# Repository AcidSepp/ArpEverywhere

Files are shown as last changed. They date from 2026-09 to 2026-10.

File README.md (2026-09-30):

# ArpEverywhere
This project aims to bring Hold and Arp to Synthesizers that do not have it.

Adding Hold and Better Arp to the Korg Minilogue (https://www.youtube.com/watch?v=hi0-8F53ltk)

## BOM
- Microcontroller
  - 1x Arduino Nano ESP32
  - 1x 32 PIN DIP Socket, 15. (wide)
- ICs
  - 2x 6n128 Optocoupler
  - 2x 8 PIN DIP Socket
- Switches
  - 4x Toggle Switch
  - 2x 12 Way Rotary Switch
- Sockets
  - 4x MIDI 5Pin DIN Panel Mount Socket
- Resistors
  - 2x 480-1KΩ
  - 2x 4.7KΩ
  - 2x 10Ω
  - 2x 20Ω
  - 2x 100Ω
  - 24x 1kΩ
  - 4x 10kΩ
  - 2x 220Ω
- Diodes
  - 2x 1n914 Diode
- Connectors
  - 6x 2.54mm 0.1" Pitch PCB Mount Screw Terminal Block
- Prototype Board

## MIDI IN Circuit
The MIDI IN circuit is based on the [MIDI IN circuit form Notes And Volts](https://www.notesandvolts.com/2015/02/midi-and-arduino-build-midi-input.html).
Modifications to make it compatible with 3.3V:
- Connect Pin 8 of the optocoupler to +5V.
- Connect Pin 6 of the optocoupler to the RX Pin and to +3.3V via a 480-1KΩ resistor.

## MIDI OUT Circuit
The MIDI OUT circuit is based on the [MIDI OUT circuit from Notes And Volts](https://www.notesandvolts.com/2015/03/midi-for-arduino-build-midi-output.html).
Modifications to make it compatible with 3.3V:
- Connect Pin 4 of the MIDI Out Socket to +3.3V via a 30Ω resistor.
- Connect Pin 5 of the MIDI Out Socket to the TX Pin via a 10Ω resistor.

## Rotary Switch Circuit
The Rotary Switch Circuit is based on [Scotty D's circuit](https://www.youtube.com/watch?v=UbnNhUDheE8&t=487s).
I do not use the capacitor, and add another 1kΩ resitor at the end of the ladder.

## Toggle Switch Circuit
I used a standard toggle switch circuit with a 10KΩ pullup-resistor.

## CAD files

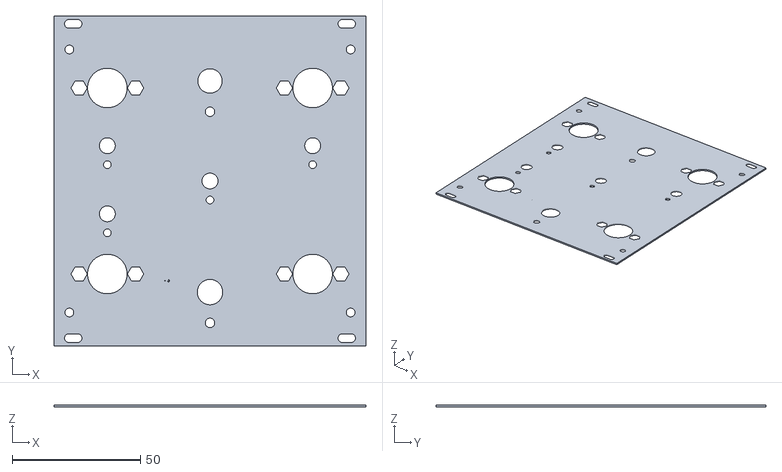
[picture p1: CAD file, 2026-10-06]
panels/frontPanel-backLayer.stl
121.6 x 128.5 x 0.8

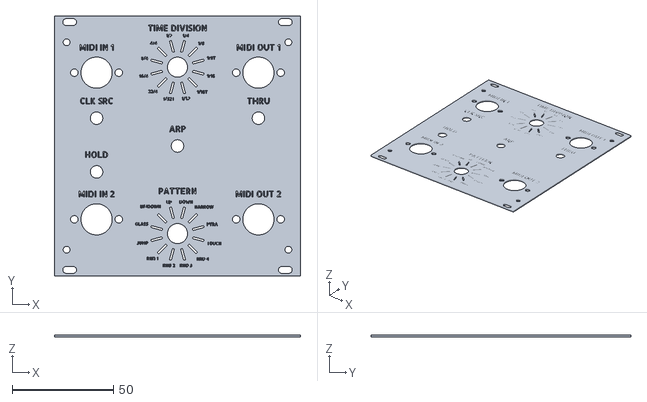
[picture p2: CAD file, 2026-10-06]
panels/frontPanel-frontLayer.stl
121.6 x 128.5 x 1.00

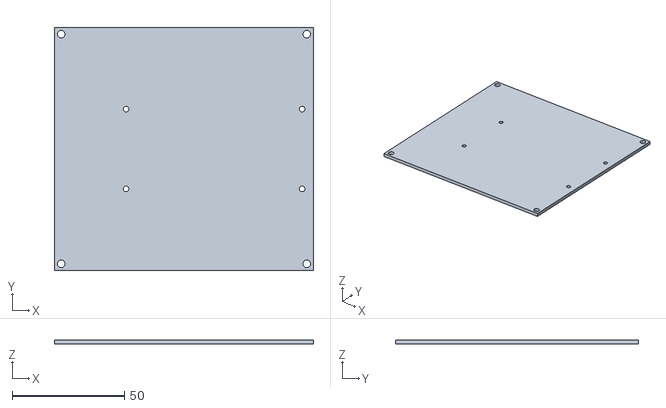
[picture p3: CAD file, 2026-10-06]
panels/backPanel.stl
115.6 x 108.5 x 2.00

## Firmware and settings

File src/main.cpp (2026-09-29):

#include <MIDI.h>

#include "Down.h"
#include "Hourglass.h"
#include "Jump.h"
#include "Narrow.h"
#include "rotarySwitch.h"
#include "timedivision.h"
#include "pattern.h"
#include "Pyramid.h"
#include "Random1.h"
#include "Random2.h"
#include "Random3.h"
#include "Random4.h"
#include "Touch.h"
#include "Up.h"
#include "UpDown.h"

constexpr bool DEBUG = false;

constexpr int MIDI_1_RX_PIN = 2;
constexpr int MIDI_1_TX_PIN = 3;
constexpr int MIDI_2_RX_PIN = 4;
constexpr int MIDI_2_TX_PIN = 5;

constexpr int HOLD_ON_OFF_SWITCH_PIN = 9;
constexpr int CLOCK_SRC_SWITCH_PIN = 8;
constexpr int ARP_ON_OFF_SWITCH_PIN = 7;
constexpr int MIDI_1_THRU_ON_OFF_SWITCH_PIN = 6;

constexpr int TIME_DIVISION_ROTARY_SWITCH_PIN = A1;
constexpr int PATTERN_ROTARY_SWITCH_PIN = A2;

HardwareSerial MidiSerial1(1);
HardwareSerial MidiSerial2(2);

MIDI_CREATE_INSTANCE(HardwareSerial, MidiSerial1, MIDI1);
MIDI_CREATE_INSTANCE(HardwareSerial, MidiSerial2, MIDI2);

static void noteOn(byte channel, byte note, byte velocity);

static void noteOff(byte channel, byte note, byte velocity);

static void handleClock();

constexpr int NOTES_ARRAY_SIZE = 128;

static bool pressedNotes[NOTES_ARRAY_SIZE];
static int pressedNotesCount = 0;
static bool sustainedNotes[NOTES_ARRAY_SIZE];
static int sustainedNotesCount = 0;
static bool holdFunctionActivated;
static bool arpActivated = true;
static int clockCounter = 0;
static TimeDivision timeDivision = _1_4;
static Pattern pattern = UP;
static bool clockFromMidi1 = true;
static bool midi1Thru = false;

static auto down = new Down();
static auto hourglass = new Hourglass();
static auto jump = new Jump();
static auto narrow = new Narrow();
static auto pyramid = new Pyramid();
static auto rnd2 = new Random2();
static auto rnd3 = new Random3();
static auto up = new Up();
static auto upDown = new UpDown();

static byte noteInputOrder[NOTES_ARRAY_SIZE];
static int noteInputOrderPointer = 0;
static auto touch = new Touch();

static void resetCounters() {
    clockCounter = 0;
    down->reset();
    hourglass->reset();
    jump->reset();
    narrow->reset();
    pyramid->reset();
    up->reset();
    upDown->reset();
}

static bool pressedNotesEmpty() {
    for (const bool pressedNote: pressedNotes) {
        if (pressedNote) {
            return false;
        }
    }
    return true;
}

static bool sustainedNotesEmpty() {
    for (const bool sustainedNote: sustainedNotes) {
        if (sustainedNote) {
            return false;
        }
    }
    return true;
}

static void clearSustainedNotes() {
    for (bool &sustainedNote: sustainedNotes) {
        sustainedNote = false;
    }
}

static void printSustainedNotes() {
    Serial.printf("Sustained Notes (%d): ", sustainedNotesCount);
    for (int i = 0; i < NOTES_ARRAY_SIZE; i++) {
        if (sustainedNotes[i]) {
            Serial.print(i);
            Serial.print(" ");
        }
    }
    Serial.println();
}

static void printPressedNotes() {
    Serial.printf("Pressed Notes (%d): ", pressedNotesCount);
    for (int i = 0; i < NOTES_ARRAY_SIZE; i++) {
        if (pressedNotes[i]) {
            Serial.print(i);
            Serial.print(" ");
        }
    }
    Serial.println();
}

static void printNoteInputOrder() {
    Serial.printf("Notes Input Order (%d): ", noteInputOrderPointer + 1);
    for (int i = 0; i < noteInputOrderPointer; i++) {
        Serial.print(noteInputOrder[i]);
        Serial.print(" ");
    }
    Serial.println();
}

static void sendNoteOn(const byte note, const byte velocity) {
    if (DEBUG) {
        Serial.printf("Sending NOTE ON: n=%d\n", note);
    }
    for (int i = 0; i < 10; ++i) {
        if (!midi1Thru) {
            MIDI1.sendNoteOn(note, velocity, i);
        }
        MIDI2.sendNoteOn(note, velocity, i);
    }
}

static void sendNoteOff(const byte note, const byte velocity) {
    if (DEBUG) {
        Serial.printf("Sending NOTE OFF: n=%d\n", note);
    }
    for (int i = 0; i < 10; ++i) {
        if (!midi1Thru) {
            MIDI1.sendNoteOff(note, velocity, i);
        }
        MIDI2.sendNoteOff(note, velocity, i);
    }
}

static void sendClock() {
    if (DEBUG) {
        Serial.printf("Sending CLOCK\n");
    }
    if (!midi1Thru) {
        MIDI1.sendClock();
    }
    MIDI2.sendClock();
}

static void sendStart() {
    if (DEBUG) {
        Serial.printf("Sending START\n");
    }
    if (!midi1Thru) {
        MIDI1.sendStart();
    }
    MIDI2.sendStart();
}

static void sendStop() {
    if (DEBUG) {
        Serial.printf("Sending STOP\n");
    }

    if (!midi1Thru) {
        MIDI1.sendStop();
    }
    MIDI2.sendStop();
}

static void handleStart() {
    if (DEBUG) {
        Serial.printf("Received START\n");
    }

    resetCounters();
    sendStart();
}

static void handleStop() {
    if (DEBUG) {
        Serial.printf("Received STOP\n");
    }

    resetCounters();
    sendStop();
}

static void midi1AllNotesOff() {
    for (int channel = 0; channel < 10; ++channel) {
        for (int note = 0; note < 128; ++note) {
            MIDI1.sendNoteOff(note, 0, channel);
        }
    }
}

static void midi2AllNotesOff() {
    for (int channel = 0; channel < 10; ++channel) {
        for (int note = 0; note < 128; ++note) {
            MIDI2.sendNoteOff(note, 0, channel);
        }
    }
}

static void setMidi1AsClockSource() {
    clockFromMidi1 = true;
    Serial.println("Clock Source: MIDI 1");
    MIDI1.setHandleClock(handleClock);
    MIDI2.setHandleClock(nullptr);

    MIDI1.setHandleStart(handleStart);
    MIDI1.setHandleStop(handleStop);
    MIDI2.setHandleStart(nullptr);
    MIDI2.setHandleStop(nullptr);
}

static void setMidi2AsClockSource() {
    clockFromMidi1 = false;
    Serial.println("Clock Source: MIDI 2");
    MIDI1.setHandleClock(nullptr);
    MIDI2.setHandleClock(handleClock);

    MIDI1.setHandleStart(nullptr);
    MIDI1.setHandleStop(nullptr);
    MIDI2.setHandleStart(handleStart);
    MIDI2.setHandleStop(handleStop);
}

void setup() {
    Serial.begin(9600);
    Serial.println("Staring...");

    MidiSerial1.begin(31250, SERIAL_8N1, MIDI_1_RX_PIN, MIDI_1_TX_PIN);
    MIDI1.begin(MIDI_CHANNEL_OMNI);
    MIDI1.setHandleNoteOn(noteOn);
    MIDI1.setHandleNoteOff(noteOff);

    pinMode(MIDI_1_THRU_ON_OFF_SWITCH_PIN, INPUT);
    if (digitalRead(MIDI_1_THRU_ON_OFF_SWITCH_PIN) == HIGH) {
        midi1Thru = true;
        Serial.println("MIDI 1 Thru: ON");
        MIDI1.turnThruOn();
    } else {
        midi1Thru = false;
        Serial.println("MIDI 1 Thru: OFF");
        MIDI1.turnThruOff();
    }
    midi1AllNotesOff();

    MidiSerial2.begin(31250, SERIAL_8N1, MIDI_2_RX_PIN, MIDI_2_TX_PIN);
    MIDI2.begin(MIDI_CHANNEL_OMNI);
    MIDI2.turnThruOff();
    midi2AllNotesOff();

    pinMode(CLOCK_SRC_SWITCH_PIN, INPUT);
    if (digitalRead(CLOCK_SRC_SWITCH_PIN) == HIGH) {
        setMidi1AsClockSource();
    } else {
        setMidi2AsClockSource();
    }

    pinMode(LED_BUILTIN, OUTPUT);
    digitalWrite(LED_BUILTIN, LOW);
    for (int i = 0; i < 5; i++) {
        delay(100);
        digitalWrite(LED_BUILTIN, HIGH);
        delay(100);
        digitalWrite(LED_BUILTIN, LOW);
    }

    pinMode(HOLD_ON_OFF_SWITCH_PIN, INPUT);
    if (digitalRead(HOLD_ON_OFF_SWITCH_PIN) == HIGH) {
        holdFunctionActivated = true;
        digitalWrite(LED_BUILTIN, HIGH);
        Serial.println("Hold: ON");
    } else {
        holdFunctionActivated = false;
        digitalWrite(LED_BUILTIN, LOW);
        Serial.println("Hold: OFF");
    }

    pinMode(PATTERN_ROTARY_SWITCH_PIN, INPUT);
    pattern = rotarySwitchNumberToPattern(getRotarySwitchNumber(analogRead(PATTERN_ROTARY_SWITCH_PIN)));
    Serial.printf("Pattern: %s\n", patternToString(pattern));

    pinMode(TIME_DIVISION_ROTARY_SWITCH_PIN, INPUT);
    timeDivision =
            rotarySwitchNumberToTimeDivision(getRotarySwitchNumber(analogRead(TIME_DIVISION_ROTARY_SWITCH_PIN)));
    Serial.printf("TimeDivision: %s\n", timeDivisionToString(timeDivision));


    pinMode(ARP_ON_OFF_SWITCH_PIN, INPUT);
    if (digitalRead(ARP_ON_OFF_SWITCH_PIN) == HIGH) {
        arpActivated = true;
        Serial.println("Arp: ON");
    } else {
        arpActivated = false;
        Serial.println("Arp: OFF");
    }

    Serial.println("Started!");
}

static void noteOffAllSustainedNotesExceptPressed() {
    for (int i = 0; i < NOTES_ARRAY_SIZE; i++) {
        if (!pressedNotes[i] && sustainedNotes[i]) {
            sendNoteOff(i, 0);
        }
    }
}

void loop() {
    const bool oldClockFromMidi1 = clockFromMidi1;
    const bool newClockFromMidi1 = digitalRead(CLOCK_SRC_SWITCH_PIN) == HIGH;

    // midi 2 was the clock source and now midi 1 is the clock source
    if (!oldClockFromMidi1 && newClockFromMidi1) {
        setMidi1AsClockSource();
        // add a little delay, to debounce the clock source switch
        delay(50);
    }

    // midi 1 was the clock source and now midi 2 is the clock source
    if (oldClockFromMidi1 && !newClockFromMidi1) {
        setMidi2AsClockSource();
        // add a little delay, to debounce the clock source switch
        delay(50);
    }

    const bool oldHoldFunctionState = holdFunctionActivated;
    const bool newHoldFunctionState = digitalRead(HOLD_ON_OFF_SWITCH_PIN) == HIGH;

    // hold function was off and is now on
    if (!oldHoldFunctionState && newHoldFunctionState) {
        holdFunctionActivated = true;
        digitalWrite(LED_BUILTIN, HIGH);

        if (DEBUG) {
            Serial.println("Switching Hold function ON");
        }

        // add a little delay, to debounce the HOLD switch
        delay(50);
    }

    // hold function is on and is now turned off
    if (oldHoldFunctionState && !newHoldFunctionState) {
        holdFunctionActivated = false;
        digitalWrite(LED_BUILTIN, LOW);

        noteOffAllSustainedNotesExceptPressed();
        clearSustainedNotes();
        noteInputOrderPointer = 0;

        if (DEBUG) {
            Serial.println("Switching Hold function OFF");
        }
        // add a little delay, to debounce the HOLD switch
        delay(50);
    }

    const bool oldArpState = arpActivated;
    const bool newArpState = digitalRead(ARP_ON_OFF_SWITCH_PIN) == HIGH;

    // arp was off and is now on
    if (!oldArpState && newArpState) {
        clockCounter = 0;
        arpActivated = true;

        if (DEBUG) {
            Serial.println("Switching Arp ON");
        }
        // add a little delay, to debounce the ARP switch
        delay(50);
    }

    // arp was on and is now off
    if (oldArpState && !newArpState) {
        clockCounter = 0;
        arpActivated = false;

        noteOffAllSustainedNotesExceptPressed();

        if (holdFunctionActivated) {
            for (int i = 0; i < NOTES_ARRAY_SIZE; i++) {
                if (sustainedNotes[i]) {
                    sendNoteOn(i, 127);
                }
            }
        } else {
            for (int i = 0; i < NOTES_ARRAY_SIZE; i++) {
                if (pressedNotes[i]) {
                    sendNoteOn(i, 127);
                }
            }
        }

        if (DEBUG) {
            Serial.println("Switching Arp OFF");
        }
        // add a little delay, to debounce the ARP switch
        delay(50);
    }

    const bool oldMidi1Thru = midi1Thru;
    const bool newMidi1Thru = digitalRead(MIDI_1_THRU_ON_OFF_SWITCH_PIN) == HIGH;

    // MIDI 1 Thru was off and is now on
    if (!oldMidi1Thru && newMidi1Thru) {
        midi1AllNotesOff();
        midi1Thru = true;
        Serial.println("MIDI 1 Thru: ON");
        MIDI1.turnThruOn();
    }

    // MIDI 1 Thru was on in is now off
    if (oldMidi1Thru && !newMidi1Thru) {
        midi1Thru = false;
        Serial.println("MIDI 1 Thru: OFF");
        MIDI1.turnThruOff();
    }

    MIDI1.read();
    MIDI2.read();
}

void noteOn(const byte channel, const byte note, const byte velocity) {
    if (DEBUG) {
        Serial.printf("Received NOTE ON: n=%d\n", note);
    }

    // if the arp is active, the note will be played automatically, so we need to prevent retriggers in that case
    // In very slow arp speeds it would take a long time until the note sounds, so we play the first not anyways.
    if (!arpActivated || sustainedNotesEmpty()) {
        sendNoteOn(note, velocity);
    }

    // the user is entering a new chord
    if (pressedNotesEmpty()) {
        for (int sustainedNotesIndex = 0; sustainedNotesIndex < 128; ++sustainedNotesIndex) {
            if (sustainedNotes[sustainedNotesIndex] && sustainedNotesIndex != note) {
                sendNoteOff(sustainedNotesIndex, 0);
            }
        }
        clearSustainedNotes();
        sustainedNotesCount = 0;
        noteInputOrderPointer = 0;
    }
    if (!pressedNotes[note]) {
        // only count the note if it is not already pressed
        pressedNotesCount++;
    }
    pressedNotes[note] = true;

    if (!sustainedNotes[note]) {
        // only count the note if it is not already sustained
        sustainedNotesCount++;
    }
    sustainedNotes[note] = true;

    noteInputOrder[noteInputOrderPointer] = note;
    if (noteInputOrderPointer < NOTES_ARRAY_SIZE) {
        noteInputOrderPointer++;
    }

    if (DEBUG) {
        printSustainedNotes();
        printPressedNotes();
        printNoteInputOrder();
    }
}

void noteOff(const byte channel, const byte note, const byte velocity) {
    if (DEBUG) {
        Serial.printf("Received NOTE OFF: n=%d\n", note);
    }

    if (!holdFunctionActivated) {
        sendNoteOff(note, velocity);
        sustainedNotes[note] = false;
        sustainedNotesCount--;
    }
    pressedNotes[note] = false;
    pressedNotesCount--;
}

static void handleClock() {
    sendClock();

    // Read the rotary switch every 1/4 note, this should suffice in accuracy
    if (clockCounter % _1_4 == 0) {
        const Pattern newPattern =
                rotarySwitchNumberToPattern(getRotarySwitchNumber(analogRead(PATTERN_ROTARY_SWITCH_PIN)));
        if (newPattern != pattern) {
            pattern = newPattern;
            Serial.printf("Pattern: %s\n", patternToString(pattern));
        }

        const TimeDivision newTimeDivision =
                rotarySwitchNumberToTimeDivision(getRotarySwitchNumber(analogRead(TIME_DIVISION_ROTARY_SWITCH_PIN)));
        if (newTimeDivision != timeDivision) {
            timeDivision = newTimeDivision;
            Serial.printf("TimeDivision: %s\n", timeDivisionToString(timeDivision));
        }
    }

    // the clock counter needs to stay in range between 0 and 32 quarter notes, as this is the biggest subdivision we support
    clockCounter = (clockCounter + 1) % _32_4;

    if (!arpActivated) {
        return;
    }

    if (clockCounter % timeDivision == 0) {
        if (DEBUG) {
            Serial.println("\n\nArp Pulse!");
            printSustainedNotes();
            printPressedNotes();
            printNoteInputOrder();
            Serial.printf("Pattern: %s\n", patternToString(pattern));
            Serial.printf("TimeDivision: %s\n", timeDivisionToString(timeDivision));
        }

        if (!sustainedNotesEmpty()) {
            if (pattern == TOUCH) {
                const int nextNote = touch->next(noteInputOrder, noteInputOrderPointer);
                int sustainedNotesIndex = 0;
                for (int note = 0; note < NOTES_ARRAY_SIZE; ++note) {
                    if (sustainedNotes[note]) {
                        // the current note is sustained
                        sendNoteOff(note, 127);
                        sustainedNotesIndex++;
                    }
                    if (note == nextNote) {
                        sendNoteOn(note, 127);
                    }
                }
            } else {
                int arpIndex = 0;
                switch (pattern) {
                    case UP:
                        arpIndex = up->next(sustainedNotesCount);
                        break;
                    case UP_DOWN:
                        arpIndex = upDown->next(sustainedNotesCount);
                        break;
                    case DOWN:
                        arpIndex = down->next(sustainedNotesCount);
                        break;
                    case NARROW:
                        arpIndex = narrow->next(sustainedNotesCount);
                        break;
                    case HOURGLASS:
                        arpIndex = hourglass->next(sustainedNotesCount);
                        break;
                    case PYRAMID:
                        arpIndex = pyramid->next(sustainedNotesCount);
                        break;
                    case JUMP:
                        arpIndex = jump->next(sustainedNotesCount);
                        break;
                    case RND_1:
                        arpIndex = Random1::next(sustainedNotesCount);
                        break;
                    case RND_2:
                        arpIndex = rnd2->next(sustainedNotesCount);
                        break;
                    case RND_3:
                        arpIndex = rnd3->next(sustainedNotesCount);
                        break;
                    case RND_4:
                        arpIndex = Random4::next(sustainedNotesCount);
                        break;
                    default:
                        arpIndex = 0;
                }

                if (DEBUG) {
                    Serial.printf("arpIndex: %d\n", arpIndex);
                }

                if (arpIndex == -1) {
                    return;
                }

                int sustainedNotesIndex = 0;
                for (int note = 0; note < NOTES_ARRAY_SIZE; ++note) {
                    if (sustainedNotes[note]) {
                        // the current note is sustained
                        sendNoteOff(note, 127);
                        if (sustainedNotesIndex == arpIndex) {
                            sendNoteOn(note, 127);
                        }
                        sustainedNotesIndex++;
                    }
                }
            }
        }
    }
}

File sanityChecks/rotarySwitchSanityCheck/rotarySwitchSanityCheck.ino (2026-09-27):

#include <MIDI.h>
#include <set>

constexpr int TIME_DIVISION_ROTARY_SWITCH_PIN = A1;
constexpr int PATTERN_ROTARY_SWITCH_PIN = A2;

const int MIDI_1_RX_PIN = 2;
const int MIDI_1_TX_PIN = 3;
const int MIDI_2_RX_PIN = 4;
const int MIDI_2_TX_PIN = 3;

constexpr int HOLD_ON_OFF_SWITCH_PIN = 9;
constexpr int CLOCK_SRC_SWITCH_PIN = 8;
constexpr int ARP_ON_OFF_SWITCH_PIN = 7;
constexpr int MIDI_1_THRU_ON_OFF_SWITCH_PIN = 6;

typedef enum {
    _32_4 = 384,
    _16_4 = 288,
    _8_4 = 192,
    _4_4 = 96,
    _1_2 = 48,
    _1_4 = 24,
    _1_8 = 12,
    _1_8T = 8,
    _1_16 = 6,
    _1_16T = 4,
    _1_32 = 3,
    _1_32T = 2,
} TimeDivision;

typedef enum {
    UP,
    DOWN,
    NARROW,
    PYRAMID,
    TOUCH,
    RND_4,
    RND_3,
    RND_2,
    RND_1,
    JUMP,
    HOURGLASS,
    UP_DOWN
} Pattern;

void setup() {
    Serial.begin(9600);

    pinMode(TIME_DIVISION_ROTARY_SWITCH_PIN, INPUT);
    pinMode(PATTERN_ROTARY_SWITCH_PIN, INPUT);

    pinMode(MIDI_1_RX_PIN, INPUT);
    pinMode(MIDI_1_TX_PIN, OUTPUT);
    pinMode(MIDI_2_RX_PIN, INPUT);
    pinMode(MIDI_2_TX_PIN, OUTPUT);

    pinMode(HOLD_ON_OFF_SWITCH_PIN, INPUT);
    pinMode(CLOCK_SRC_SWITCH_PIN, INPUT);
    pinMode(ARP_ON_OFF_SWITCH_PIN, INPUT);
    pinMode(MIDI_1_THRU_ON_OFF_SWITCH_PIN, INPUT);
}

static int getRotarySwitchNumber(const int sensorValue) {
    if (sensorValue < 149) {
        return 0;
    }
    if (sensorValue >= 150 && sensorValue <= 438) {
        return 1;
    }
    if (sensorValue >= 450 && sensorValue <= 799) {
        return 2;
    }
    if (sensorValue >= 800 && sensorValue <= 1149) {
        return 3;
    }
    if (sensorValue >= 1150 && sensorValue <= 1499) {
        return 4;
    }
    if (sensorValue >= 1500 && sensorValue <= 1799) {
        return 5;
    }
    if (sensorValue >= 1800 && sensorValue <= 2099) {
        return 6;
    }
    if (sensorValue >= 2100 && sensorValue <= 2399) {
        return 7;
    }
    if (sensorValue >= 2400 && sensorValue <= 2799) {
        return 8;
    }
    if (sensorValue >= 2800 && sensorValue <= 3199) {
        return 9;
    }
    if (sensorValue >= 3200 && sensorValue <= 3699) {
        return 10;
    }
    if (sensorValue >= 3700) {
        return 11;
    }
    return 0;
}

TimeDivision rotarySwitchNumberToTimeDivision(const int rotarySwitchNumber) {
    switch (rotarySwitchNumber) {
        case 0:
            return _4_4;
        case 1:
            return _1_2;
        case 2:
            return _1_4;
        case 3:
            return _1_8;
        case 4:
            return _1_8T;
        case 5:
            return _1_16;
        case 6:
            return _1_16T;
        case 7:
            return _1_32;
        case 8:
            return _1_32T;
        case 9:
            return _32_4;
        case 10:
            return _16_4;
        case 11:
            return _8_4;
        default:
            return _4_4;
    }
}

const char *timeDivisionToString(const TimeDivision timeDivision) {
    switch (timeDivision) {
        case _32_4:
            return "_32_4";
        case _16_4:
            return "_16_4";
        case _8_4:
            return "_8_4";
        case _4_4:
            return "_4_4";
        case _1_2:
            return "_1_2";
        case _1_4:
            return "_1_4";
        case _1_8:
            return "_1_8";
        case _1_8T:
            return "_1_8T";
        case _1_16:
            return "_1_16";
        case _1_16T:
            return "_1_16T";
        case _1_32:
            return "_1_32";
        case _1_32T:
            return "_1_32T";
        default:
            return "";
    }
}

Pattern rotarySwitchNumberToPattern(const int rotarySwitchNumber) {
    switch (rotarySwitchNumber) {
        case 0:
            return NARROW;
        case 1:
            return DOWN;
        case 2:
            return UP;
        case 3:
            return UP_DOWN;
        case 4:
            return HOURGLASS;
        case 5:
            return JUMP;
        case 6:
            return RND_1;
        case 7:
            return RND_2;
        case 8:
            return RND_3;
        case 9:
            return RND_4;
        case 10:
            return TOUCH;
        case 11:
            return PYRAMID;
        default:
            return UP;
    }
}

const char *patternToString(const Pattern pattern) {
    switch (pattern) {
        case UP:
            return "UP";
        case DOWN:
            return "DOWN";
        case NARROW:
            return "NARROW";
        case PYRAMID:
            return "PYRAMID";
        case TOUCH:
            return "TOUCH";
        case RND_4:
            return "RND_4";
        case RND_3:
            return "RND_3";
        case RND_2:
            return "RND_2";
        case RND_1:
            return "RND_1";
        case JUMP:
            return "JUMP";
        case HOURGLASS:
            return "HOURGLASS";
        case UP_DOWN:
            return "UP_DOWN";
        default:
            return "";
    }
}

void loop() {
    delay(1000);
    const int patternRawValue = analogRead(PATTERN_ROTARY_SWITCH_PIN);
    Serial.printf("Pattern Raw Value %d\n", patternRawValue);
    Serial.printf("Pattern: %s\n", patternToString(rotarySwitchNumberToPattern(getRotarySwitchNumber(patternRawValue))));

    const int timeDivisionRawValue = analogRead(TIME_DIVISION_ROTARY_SWITCH_PIN);
    Serial.printf("TimeDivision Raw Value %d\n", timeDivisionRawValue);
    Serial.printf("TimeDivision: %s\n", timeDivisionToString(rotarySwitchNumberToTimeDivision(getRotarySwitchNumber(timeDivisionRawValue))));
}

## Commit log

2026-09-03 PoC: show midi notes via internal LED
2026-09-03 fix all sanity checks
    [arpEverywhere.ino, midiInOutSanityCheck.ino, midiInSanityCheck.ino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]
2026-09-05 add switchSanityCheck.ino
2026-09-05 implement switch for hold function
2026-09-09 guard Serial prints with DEBUG
2026-09-12 fix no note appearing with very slow arp speeds
    [main.cpp]
2026-09-21 migrate to Arduino Nano ESP32
2026-09-21 add hold, clockSrc, arp and thru switches to switchSanityCheck.ino
2026-09-22 update main.cpp to new setup change rotary switch values as there is now a 1K resitor in front of the rotary switch to avoid shorts
    [main.cpp, rotarySwitchSanityCheck.ino]
2026-09-22 implement arp switch
2026-09-22 implement clock source switch
2026-09-22 replace set-based implementation with array-based implementation
    [main.cpp]
2026-09-22 fix bugged NOTE OFF when entering new chord
    [main.cpp]
2026-09-27 fix wrong counting of sustained notes and pressed notes
    [main.cpp, rotarySwitchSanityCheck.ino]
2026-09-29 add front panel svg and stl
    [backLayer.stl, frontLayer.stl]
2026-09-29 fix CLOCK and Transport forwarding
    [main.cpp, midiInOutSanityCheck.ino]
2026-09-30 add build video to README.md add BOM to README.md
2026-09-30 update README.md add schematic
    [arpEverywhere.kicad_sch]
2026-10-02 update naming of panels add backPanel.stl
    [backPanel.stl, frontPanel-backLayer.stl, frontPanel-frontLayer.stl]
2026-10-02 fix wrong wiring of input switch circuit
    [arpEverywhere.kicad_sch]
2026-10-06 make panels eurorack compatible (tested with laser cut)
    [arpEverywhereWithConnectors.kicad_pcb, arpEverywhereWithConnectors.kicad_sch, backPanel.stl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]
